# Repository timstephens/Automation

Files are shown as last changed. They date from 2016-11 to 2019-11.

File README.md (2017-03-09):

# Automation
Home automation and monitoring based on MQTT and ESP8266. There are a series of nodes, which can function as a producer or consumer of messages (or both). Right now, there are three types of node:

* Temperature sensor nodes, which have a small temperature sensor and broadcast the reading every few seconds (a PCB exists for these).
* Switcher nodes, which contain a relay to switch stuff on and off (a PCB exists for low-voltage switching)
* Message board nodes, which contain an LED matrix display so that output can be communicated to the real world.

These nodes each connect to an MQTT broker, which could be something like Mosquitto running on a Raspberry Pi. There's then some glue logic that needs to exist (e.g. NodeRed) that allows the whole system to respond to changes on the inputs. Some work is requred to get all this working, and this is left as an exercise for the student.

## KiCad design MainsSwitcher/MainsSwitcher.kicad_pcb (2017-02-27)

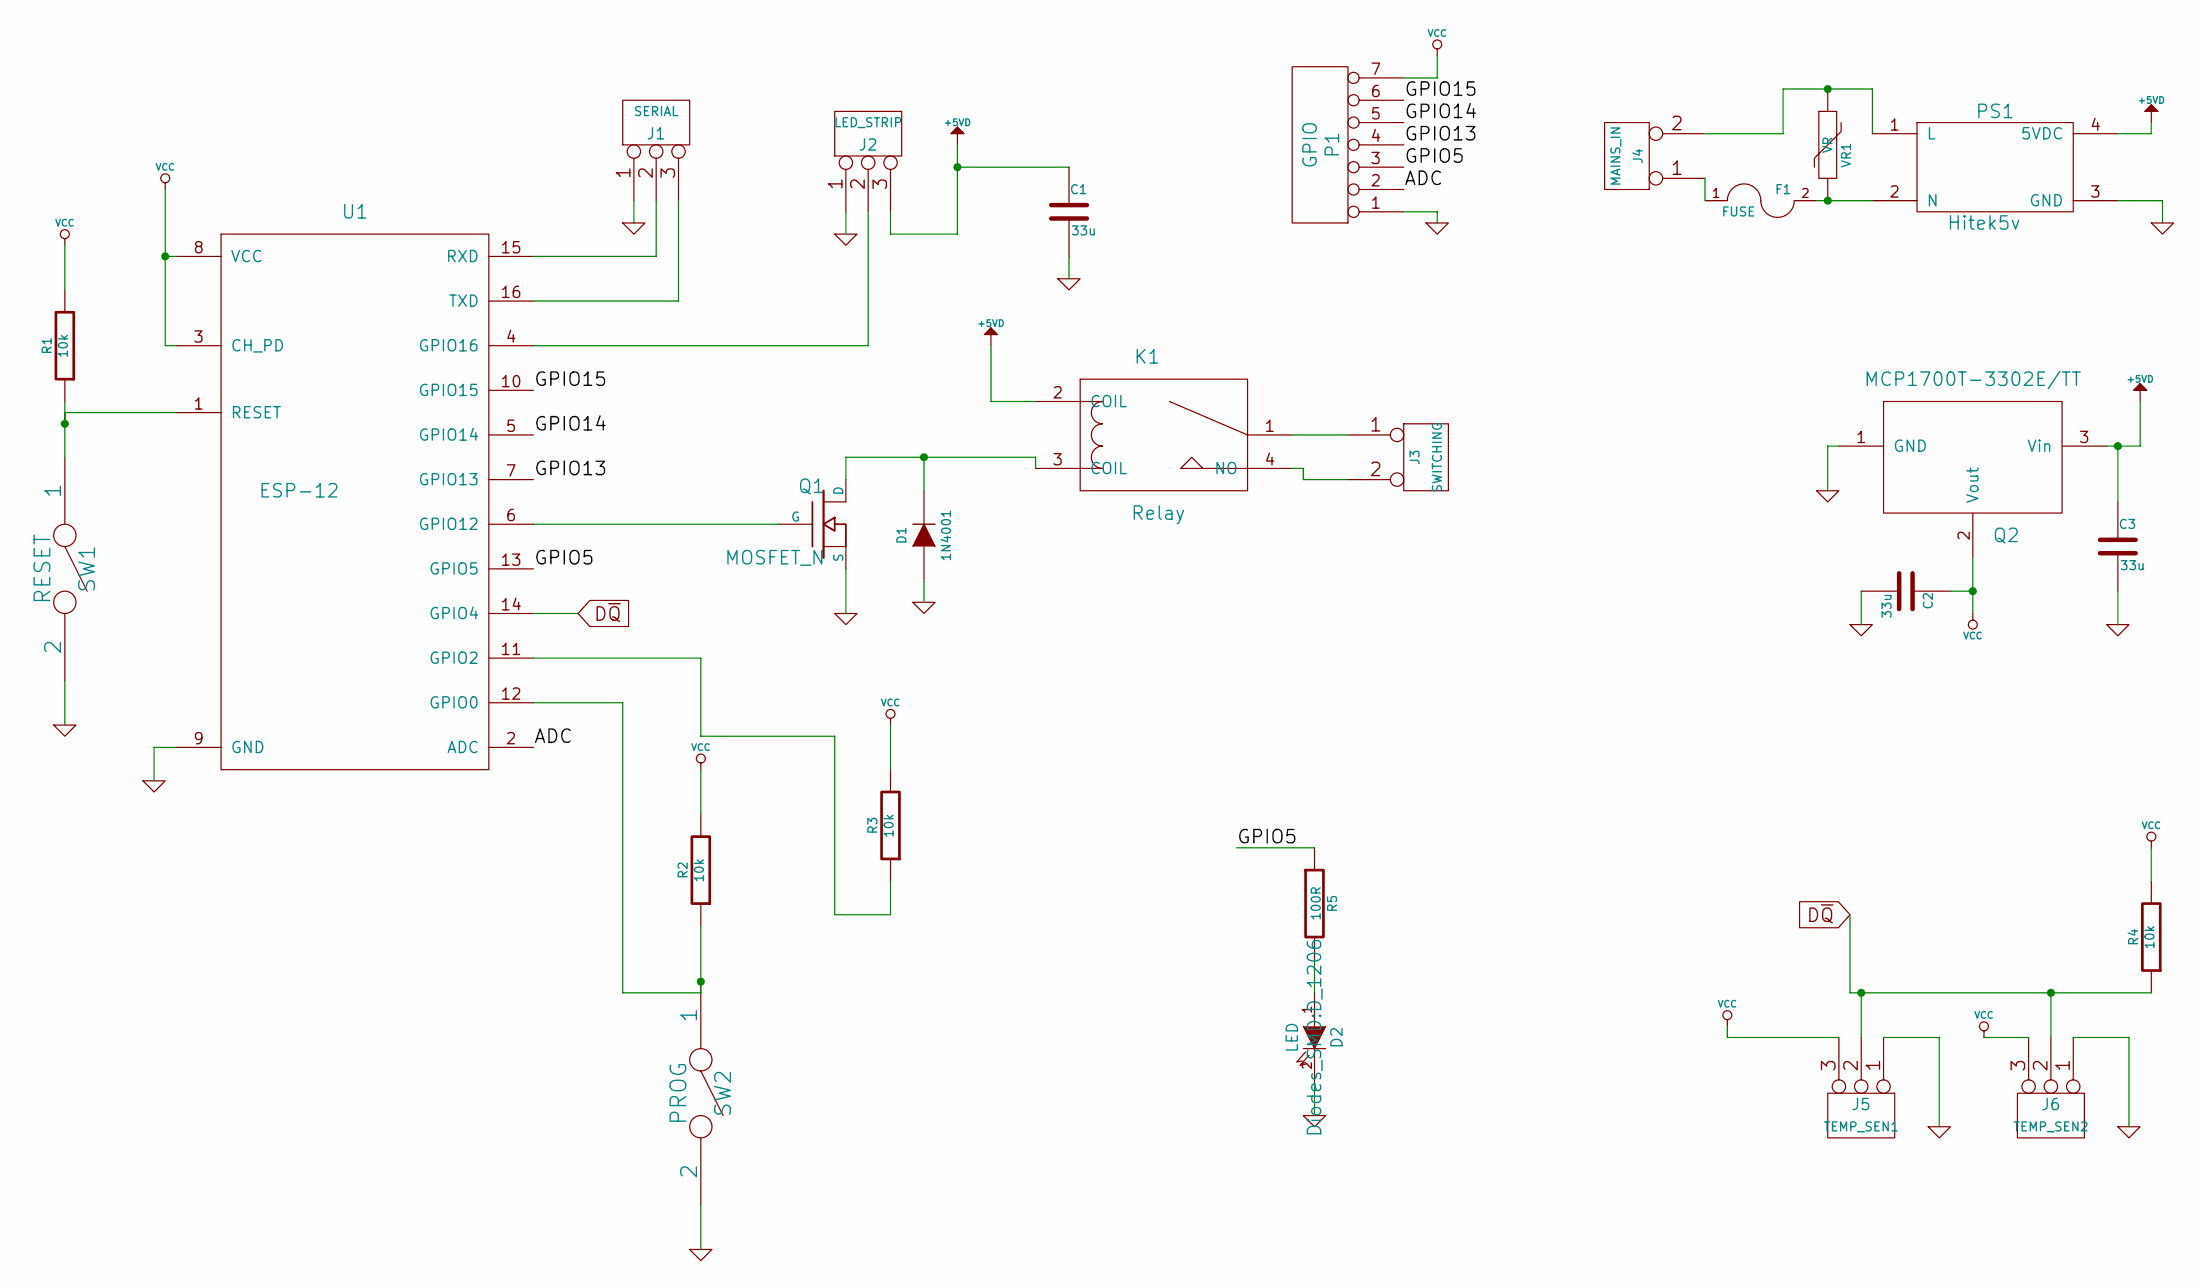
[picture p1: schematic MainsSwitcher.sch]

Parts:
C1, C2, C3: 33u; C_1206_HandSoldering
D1: 1N4001; D_SMA-SMB_Universal_Handsoldering
D2: LED; D_1206
F1: FUSE; Schurter_Fuseholder(20x5mm)0031.8211
J1: SERIAL; Molex_KK-6410-03_03x2.54mm_Straight
J2: LED_STRIP; Molex_KK-6410-03_03x2.54mm_Straight
J3: SWITCHING; PhoenixContact_PT1,5-2-5.0-V
J4: MAINS_IN; PhoenixContact_PT1,5-2-5.0-V
J5: TEMP_SEN1; Molex_KK-6410-03_03x2.54mm_Straight
J6: TEMP_SEN2; Molex_KK-6410-03_03x2.54mm_Straight
K1: Relay; COTO_SIP_ReedRelay-9007-05-00
P1: GPIO; Molex_KK-6410-07_07x2.54mm_Straight
PS1: Hitek5v; HLK-P0X
Q1: MOSFET_N; SOT-23_Handsoldering
Q2: MCP1700T-3302E/TT; SOT-23
R1, R2, R3, R4: 10k; R_1206_HandSoldering
R5: 100R; R_1206_HandSoldering
SW1: RESET; SW_PUSH_6mm
SW2: PROG; SW_PUSH_6mm
U1: ESP-12
VR1: VR; MOV-EPCOS-B72214S0421K101

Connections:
+5VD: C1.1, C3.1, J2.3, K1.2 (COIL), PS1.4 (5VDC), Q2.3 (Vin)
/ADC: P1.2, U1.2 (ADC)
/GPIO5: P1.3, R5.1, U1.13 (GPIO5)
/GPIO13: P1.4, U1.7 (GPIO13)
/GPIO14: P1.5, U1.5 (GPIO14)
/GPIO15: P1.6, U1.10 (GPIO15)
D~Q: J5.2 (PM), J6.2 (PM), R4.1, U1.14 (GPIO4)
GND: C1.2, C2.2, C3.2, D1.1 (A), D2.2 (K), J1.1, J2.1, J5.1, J6.1, P1.1, PS1.3 (GND), Q1.S, Q2.1 (GND), SW1.2, SW2.2, U1.9 (GND)
unnamed: D1.2 (K), K1.3 (COIL), Q1.D
unnamed: D2.1 (A), R5.2
unnamed: F1.1, J4.1
unnamed: F1.2, PS1.2 (N), VR1.2
unnamed: J1.2 (PM), U1.15 (RXD)
unnamed: J1.3, U1.16 (TXD)
unnamed: J2.2 (PM), U1.4 (GPIO16)
unnamed: J3.1, K1.1
unnamed: J3.2 (PM), K1.4 (NO)
unnamed: J4.2 (PM), PS1.1 (L), VR1.1
unnamed: Q1.G, U1.6 (GPIO12)
unnamed: R1.1, SW1.1, U1.1 (RESET)
unnamed: R2.1, SW2.1, U1.12 (GPIO0)
unnamed: R3.1, U1.11 (GPIO2)
VCC: C2.1, J5.3, J6.3, P1.7, Q2.2 (Vout), R1.2, R2.2, R3.2, R4.2, U1.3 (CH_PD), U1.8 (VCC)

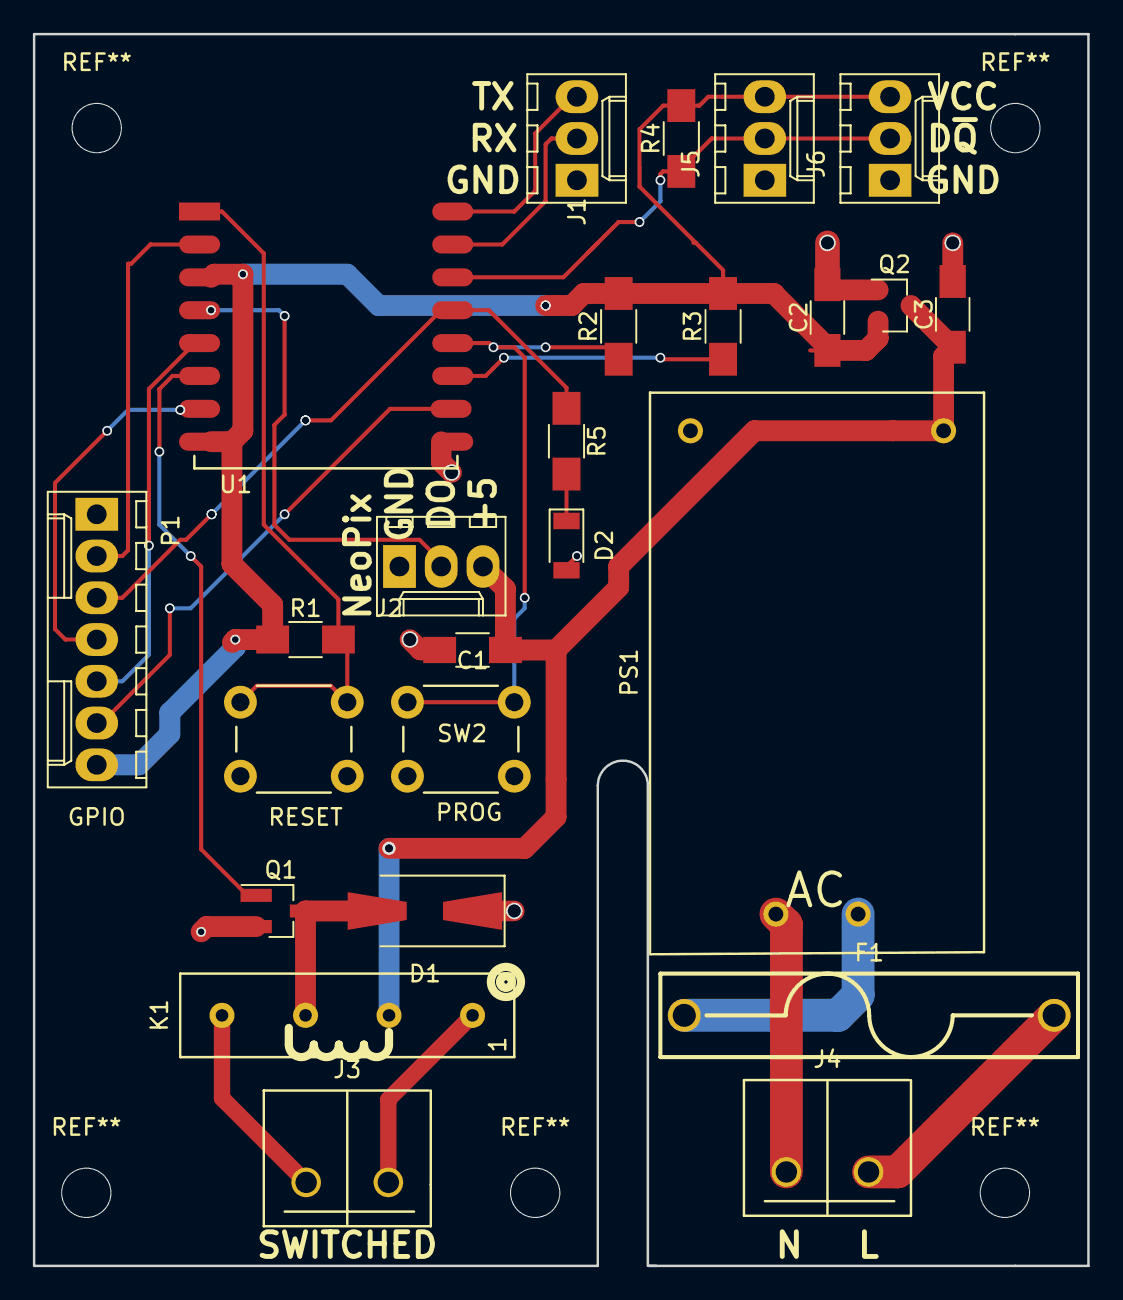
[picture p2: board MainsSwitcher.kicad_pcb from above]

Board: 2 copper layers, 64.1 x 74.9 mm, 25 parts (0 on the bottom side), 23 nets.

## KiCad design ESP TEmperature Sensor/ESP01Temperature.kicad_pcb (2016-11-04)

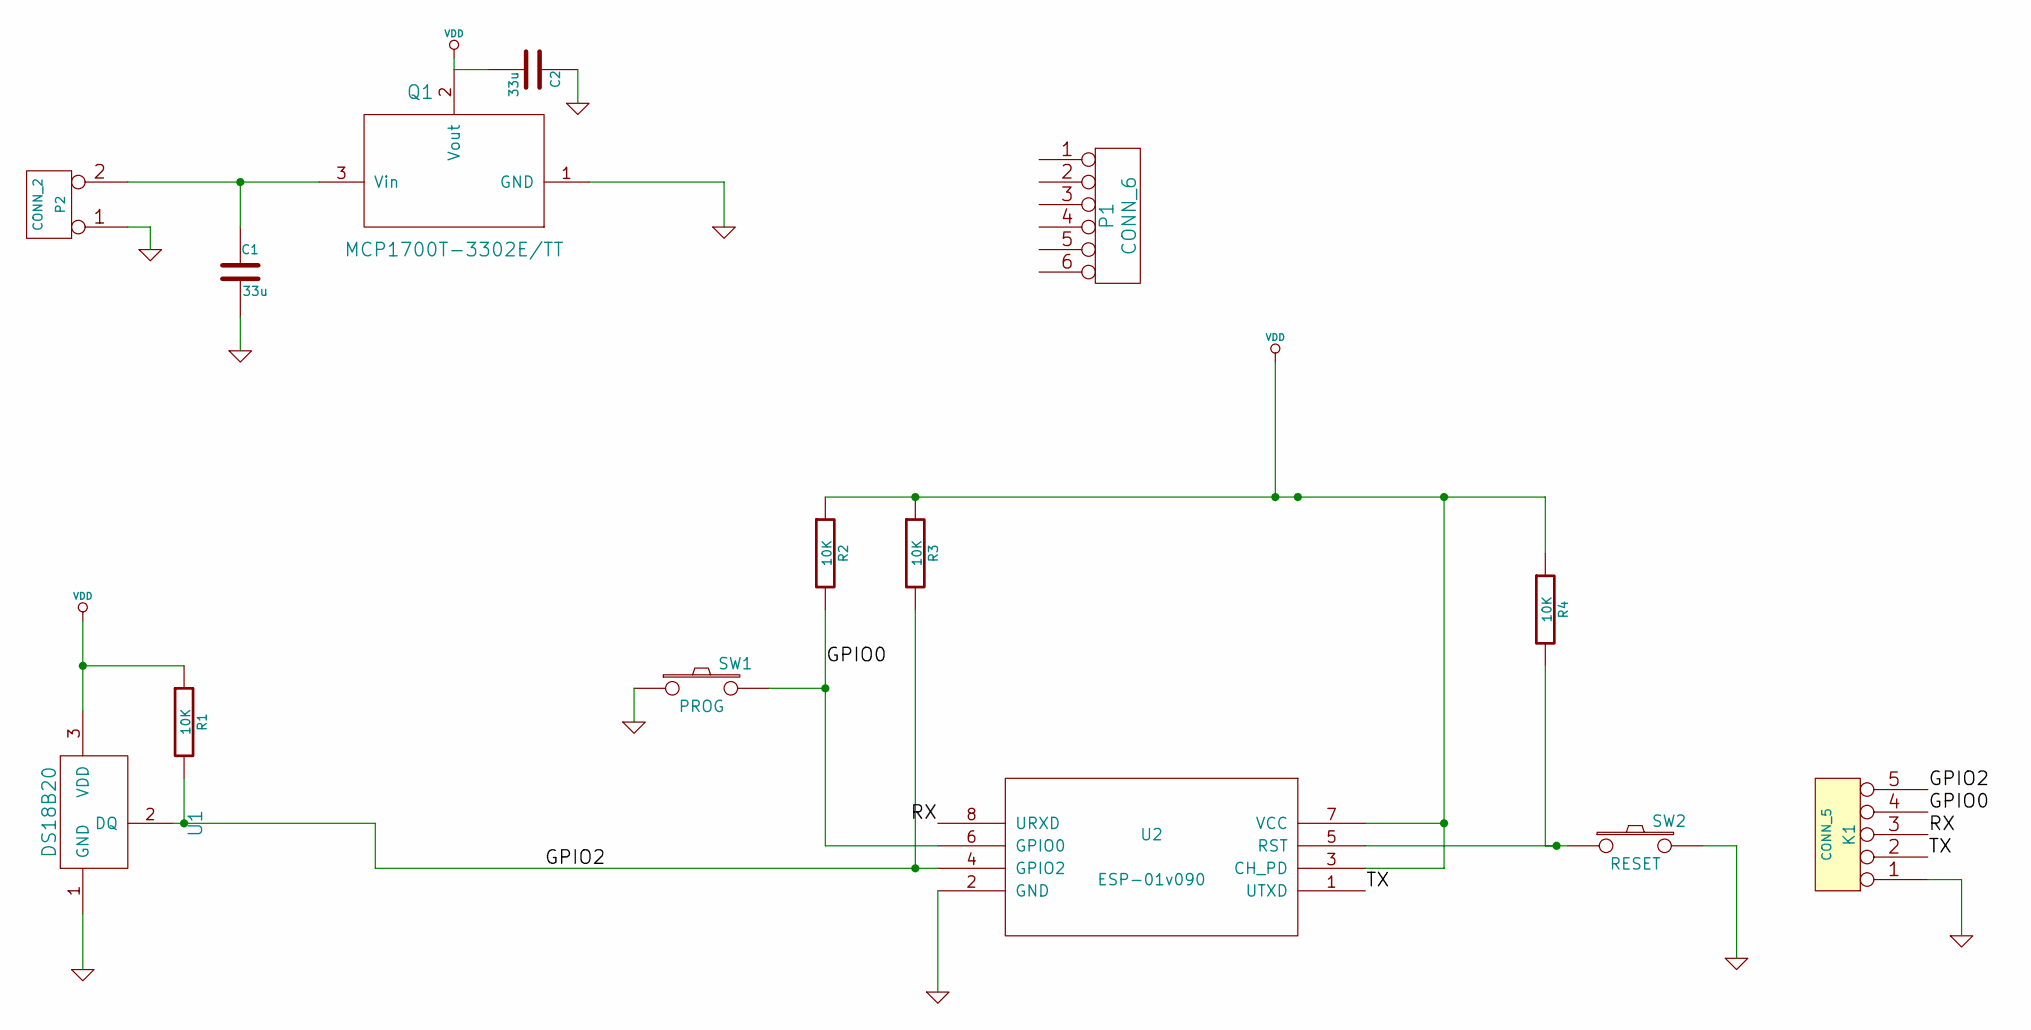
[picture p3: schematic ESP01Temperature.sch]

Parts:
C1, C2: 33u; C_1206_HandSoldering
K1: CONN_5; Molex_KK-6410-05_05x2.54mm_Straight
P1: CONN_6; Molex_KK-6410-06_06x2.54mm_Straight
P2: CONN_2; Pin_Header_Angled_1x02
Q1: MCP1700T-3302E/TT; SOT-23
R1, R2, R3, R4: 10K; R_1206_HandSoldering
SW1: PROG; SW_PUSH_6mm
SW2: RESET; SW_PUSH_6mm
U1: DS18B20; TO-92_Molded_Narrow
U2: ESP-01v090; ESP-01

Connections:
/GPIO0: K1.4, R2.2, SW1.2, U2.6 (GPIO0)
/GPIO2: K1.5, R1.2, R3.2, U1.2 (DQ), U2.4 (GPIO2)
/RX: K1.3, U2.8 (URXD)
/TX: K1.2, U2.1 (UTXD)
GND: C1.2, C2.1, K1.1, P2.1, Q1.1 (GND), SW1.1, SW2.2, U1.1 (GND), U2.2 (GND)
unnamed: C1.1, P2.2 (PM), Q1.3 (Vin)
unnamed: R4.2, SW2.1, U2.5 (RST)
VDD: C2.2, Q1.2 (Vout), R1.1, R2.1, R3.1, R4.1, U1.3 (VDD), U2.3 (CH_PD), U2.7 (VCC)

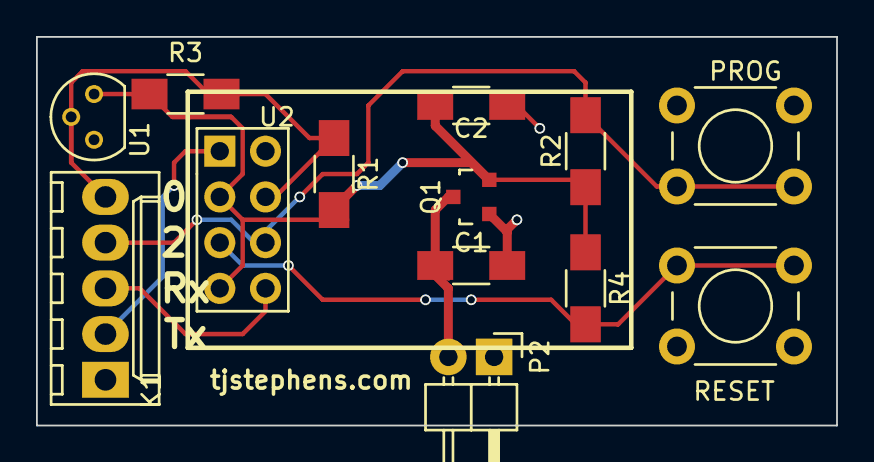
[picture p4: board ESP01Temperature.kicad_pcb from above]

Board: 2 copper layers, 44.4 x 21.6 mm, 13 parts (0 on the bottom side), 8 nets.

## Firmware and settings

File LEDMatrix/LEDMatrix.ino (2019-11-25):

#include "LedControl.h"
#include "font.h"
#include <WiFiClient.h>
#include <ESP8266mDNS.h>
#include <PubSubClient.h>

const char* ssid = "virginmedia0465902";
const char* password = "hunter77";
////MDNSResponder mdns;

String pl; //Somewhere to store the data forthe display?
#define ARRAYCOLS 128
#define NUMARRAYS  8
#define DISPLENGTH 10
// Parameters in LedControl are DIN, CLK, CS
//LedControl lc = LedControl(12, 11, 10, NUMARRAYS);// ARDUINO VERSION
LedControl lc = LedControl(14, 13, 12, NUMARRAYS); //ESP03  Version

/* we always wait a bit between updates of the display */
unsigned long delaytime = 500;

//Button on GPIO 2, pulled high with 470k. Short to ground to register a button press.
int button = 2;

// Update these with values suitable for your network.
byte mac[]    = {  0xDE, 0xED, 0xBA, 0xFE, 0xFE, 0xED };
//IPAddress ip(192.168.0.9);
IPAddress server(192, 168, 0, 8);
//8*************
void callback(char* topic, byte* payload, unsigned int length) {
  pl = ""; //This is a global string because Arduino.
  Serial.print("Message arrived [");
  Serial.print(topic);
  Serial.print("] ");
  for (int i = 0; i < length; i++) {
    Serial.print((char)payload[i]);
    pl += String((char)payload[i]);
  }
  Serial.println();
}

WiFiClient ethClient;
PubSubClient client(ethClient);

void reconnect() {
  // Loop until we're reconnected
  while (!client.connected()) {
    Serial.print("Attempting MQTT connection...");
    // Attempt to connect
    if (client.connect("arduinoClient")) {
      Serial.println("connected");
      // Once connected, publish an announcement...
      client.publish("/control", "/message ready");
      // ... and resubscribe
      client.subscribe("/message");
    } else {
      Serial.print("failed, rc=");
      Serial.print(client.state());
      Serial.println(" try again in 5 seconds");
      // Wait 5 seconds before retrying
      delay(5000);
    }
  }
}

//***************************



void setup() {
  Serial.begin(115200);
  Serial.println("connected");
  
  /*
    The MAX72XX is in power-saving mode on startup,
    we have to do a wakeup call
  */
  for (int devices = 0; devices < NUMARRAYS; devices++)
  {
    lc.shutdown(devices, false);

    /* Set the brightness to a medium values */
    lc.setIntensity(devices, NUMARRAYS);
    /* and clear the display */
    lc.clearDisplay(devices);
  }
  WiFi.begin(ssid, password);
  while (WiFi.status() != WL_CONNECTED) {
    delay(500);
    Serial.print(".");
  }//*/

  client.setServer(server, 1883);
  client.setCallback(callback);
  pinMode(button, INPUT);
}

void printChar(String row1Data) {

  /* ****************************************************
    Build up the text that you want to write to the screen
    into a buffer, made up of ARRAYCOLS chars (corresponding to a
    column each).
    Then write the buffer out to the display, reconfiguring
    it as appropriate for the display layout.

    TODO: NEEDS SOME VALIDATION TO PREVENT BUFFER OVERFLOW
  **************************************************** */

  char buf[ARRAYCOLS];
  int c, i, count;
  int array, col;

  //Initialise the buffer so it's all zeros when we begin
  memset(buf, 0, sizeof(buf));

  count = 0; //counter for the current buffer position
  //String row1Data = "test";
  //For each character
  for (int index = 0; index < row1Data.length(); index++) {
    c = row1Data.charAt(index);
    for (int i = 0; i < 6; i++) { //For each column within a character
      if (count > ARRAYCOLS) {
        break;  //Once there are more columns than in the LED array, stop writing. This is to stop a crasher on ESP03
      }
      buf[count] =  pgm_read_byte(&ASCII[(int)c][i]); //We're bit-shifting the data in one column at a time
      count++;
    }


  }
  //Once the buffer is full, write the data out to the LED array
  //There are 64 columns, so do a modulus%8 of the current index in the buffer. The mod is the array number and the remainder is the column.
  for (int i = 0; i < ARRAYCOLS; i++) {
    array = i / 8;
    col = 7 - (i % 8); //The column order is the reverse of the display order, so need to reverse it here by subtracting from 7.
    //i.e. col7 needs to be sent as col 1, etc.
    lc.setColumn(array, col, buf[i]);
  }
}


void loop() {
  int pos;


  //If there's a message that's longer than the display length, we'll scroll through it once, then display the first few characters on the display until it's updated again.
  //This means that you'll need to handle this case on the MQTT server end (probably within NodeRed, or whatever)
  if (pl.length() > DISPLENGTH) {
    pos = DISPLENGTH;
    Serial.println("Scrolling...");

    while (pos <= pl.length()) {
      printChar(pl.substring(pos - DISPLENGTH, pos));
      pos++;
      delay(500);
    }
    delay(1000);
    pl = pl.substring(0, DISPLENGTH); //Do this so that a long string can't prevent the pl from being updated. A long strng could cause the code to be stuck in this loop for ages because the window where a new string can be sent is very whort.

  }

  printChar(pl);  //str(payload) should return a string from the payload, assuming that the payload is null terminated...
  
  
  //If there's a button press, send a message to tell the broker that it's happened. A decision about what that means will be made there...
  int inputButton = digitalRead(button);
  
  if (inputButton == 0) {
    client.publish("/buffer", "button");  //Publish that a button was pressed, and signal it to the buffer workflow in Nodered.
  } else {
    Serial.println("buttonUp");
  }
  
  delay(1000);
  //  for (int devices = 0; devices < NUMARRAYS; devices++) {
  //    lc.clearDisplay(devices);
  //  }
  Serial.println("Main Loop");
  if (!client.connected()) {
    reconnect();
  }
  client.loop();
}

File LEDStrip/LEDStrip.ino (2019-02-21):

#include <Adafruit_NeoPixel.h>
#include <WiFiClient.h>
//#include <ESP8266mDNS.h>
#include <PubSubClient.h>
#include <DallasTemperature.h>
#include <OneWire.h>
#include <ESP.h>
#include <ESP8266WebServer.h>
#include <EEPROM.h>

#include "wifiSetup.h"

#define LED_PIN 4
#define ONE_WIRE_BUS 5
//Set up the NeoPixel Library

#define LED_STRIP 16
#define NUMPIXELS      5
Adafruit_NeoPixel pixels = Adafruit_NeoPixel(NUMPIXELS, LED_STRIP, NEO_GRB + NEO_KHZ800);

int delayval = 500; // delay for half a second


//Turn on the temperature sensors
OneWire oneWire(ONE_WIRE_BUS);
DallasTemperature sensors(&oneWire);


// Update these with values suitable for your network.
IPAddress server(192, 168, 0, 8);  //Default, but is set on 'connect' from values stored in the EEPROM

void callback(char* topic, byte* payload, unsigned int length) {

  Serial.print("Got message :");
  for (int i = 0; i < length; i++) {
    Serial.print((char)payload[i]);
  }
  Serial.println();
}

WiFiClient ethClient;
PubSubClient client(ethClient);

void reconnect() {
  //This connects to the MQTT broker
  // Loop until we're reconnected
  while (!client.connected()) {
    Serial.print("Attempting MQTT connection...");
    // Attempt to connect
    if (client.connect(clientName.c_str())) {
      Serial.println("connected");
      // Once connected, publish an announcement...
      client.publish("/control", clientName.c_str());
      // ... and resubscribe
      client.subscribe("/control/#");
    } else {
      //      Serial.print("failed, rc=");
      //      Serial.print(client.state());
      //      Serial.println(" try again in 5 seconds");
      // Wait 5 seconds before retrying
      delay(5000);
    }

    //The code gets trapped in this loop if the network settings are not correct, or if the broker IP is wrong. Provide an opportunity to escape to the settings server
    if (digitalRead(0) == 0) {
      startSoftAP();
    }
    if (serverStatus == 1) {
      configServer.handleClient();
    }
  }
}

//***************************


void setup() {

  EEPROM.begin(512); //Begin the EEPROM session

  int host1, host2, host3, host4; //the IP addresses of the mqtt broker.
  serverStatus = 0; //This is the default case, where there is no server started for config.
  Serial.begin(115200);
  //  Serial.println("connected");

  //Generate the MQTT clientname from the MAC Address.
  uint8_t mac[6];
  WiFi.macAddress(mac);

  //  String dn;
  //  for (int i = deviceNameAddr; i < 32; ++i)
  //  {
  //    dn += char(EEPROM.read(i));
  //  }

  clientName += "LEDStrip-";
  clientName += macToStr(mac);

  connectToWiFi();

  if (WiFi.status() != WL_CONNECTED) {
    //Need to serve up a page that offers the opportunity to enter server details etc.
    //    Serial.println("Failed to connect to WiFi netowrk.");
    //    Serial.println("Change to configuration mode");

    // Start the server
    startSoftAP();  //sets serverStatus = 1;



  } else {
    //Serial.println("Connected to WiFi network ");
    //Serial.println(esid);
    client.setServer(server, 1883);
    client.setCallback(callback);
    //Stop the softAP if it's running, and disconnect all stations.
    //WiFi.softAPdisconnect(true);
  }
  //Setup the MQtt broker.
  host1 = EEPROM.read(IPAddr);  //Get the IP Address.
  host2 = EEPROM.read(IPAddr + 4);
  host3 = EEPROM.read(IPAddr + 8);
  host4 = EEPROM.read(IPAddr + 12);
  server = IPAddress(host1, host2, host3, host4);
  // Serial.print("Broker IP=");
  //Serial.println(server);
  //  //Start the temperature sensor


  //Serial.print("Number DS18b20 devices: ");
  //Serial.println(sensors.getDeviceCount(), DEC);
  //setup some IO on various pins
  pinMode(LED_PIN, OUTPUT);

  pixels.begin(); // This initializes the NeoPixel library.
  sensors.begin(); //initialise the temperature sensors
}


void loop() {
  if (WiFi.status() != WL_CONNECTED) {
    connectToWiFi();
  }

  if (serverStatus == 0) {  //Only want to handle the webserver configuration stuff if it's running, so this handles the case if it's not.
    char buffer[10];
    sensors.requestTemperatures();
    // After we get the temperatures, we can print them here.
    // We use the function ByIndex, and as an example get the temperature from the first sensor only.
    for (int i = 0; i < sensors.getDeviceCount(); i++) {
      Serial.print("Temperature for the device ");
      Serial.print(i, DEC);
      Serial.println(" is: ");
      Serial.println(sensors.getTempCByIndex(i));
      String tempC = String(sensors.getTempCByIndex(i));

      if (!client.connected()) {
        reconnect();
      } else {
        Serial.println("Publishing");
        String publishTopic = "/temperature/";
        publishTopic += clientName;
        publishTopic += "/";
        publishTopic += i; //Append the sensor number to the channel data
        client.publish(publishTopic.c_str(), (char *)tempC.c_str());
        delay(2000);

        //TODO: Fix this deepsleep bug
        //Serial.println("Done, Sleeping 10s");

        //ESP.deepSleep(10000000, WAKE_RF_DEFAULT);
      }
    }

    client.loop();

  } else {
    //Serial.printf("Stations connected = %d\n", WiFi.softAPgetStationNum());
    configServer.handleClient();
  }
  if (digitalRead(0) == 0) {
    //Serial.println("Prog pushed, running config server");
    startSoftAP();
  }


  for (int i = 0; i < NUMPIXELS; i++) {

    // pixels.Color takes RGB values, from 0,0,0 up to 255,255,255
    pixels.setPixelColor(i, pixels.Color(0, 150, 0)); // Moderately bright green color.

    pixels.show(); // This sends the updated pixel color to the hardware.

    delay(delayval); // Delay for a period of time (in milliseconds).

  }
  delay(2000);
}

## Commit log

2015-04-27 Initial Commit
    MQTT_Publish contains some code that connects to a mosquitto server and
    publishes the temperature measured on a DS18B20. The code then holds a
    delay and pushes an update every 10s. The whole thing may or may not
    work depending on whether the connection remains open or not. A version
    very similar to this (but without the ESP.deepsleep() on line 96 worked
    for 10hours without failure in the initial test.
2015-06-29 Add SensorTelemetry
    which is supposed to be able to get the temperature from a DHT22 T/H
    sensor and send it over RF24 link.
2015-07-08 Add new receiver code
    Not yet functional —receiver does not appear togged anything from
    radio.available on the pong side of the system.
    Radio on ping side claims about 50% success rate. Something is fibbing
    to me…
2015-07-18 LED Matrix as first step towards MQTT display
    LED Matrix allows writing of arbitrary characters to a set of LED
    matrix displays controlled by MAX7219 chips. The particular orientation
    of the displays may differ (they’re from eBay).
    Added font.h, which is cribbed from
    http://www.hwsw.no/snippets/5x7_LCD_font.php
    NB: To run this on an ESP8266, you need to make a change like this to
    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
2015-07-19 Working display of millis() on ESP8266
2015-07-19 Wifi connection works, broker connection fails
    WiFi network connection starts up with the system, and remains up (ping
    proves this).
    Added MQTT stuff, but there’s nothing working here. Issue seems to be
    that it doesn’t connect to the broker (or fails). Nothing shows on
    mosquito_sub on the broker end either, so it’s a double-ended fail.
    Counter increments (slowly) since there’s a delay incurred with
    connecting to the broker, and then failing.
    [LEDMatrix.ino]
2015-07-20 rename client to prevent naming clash
    created function to clear displays
    More debugging
    [LEDMatrix.ino]
2015-08-24 Trying to get the wifi and broker to connect
    [LEDMatrix.ino]
2015-08-24 Revert 3d2e02d..628b364
    This rolls back to commit 3d2e02dde2a0b45e62e666465407c8845c5f7a7e.
    [LEDMatrix.ino]
2016-03-28 Working to display millis(), and connects to wifi
2016-03-28 Getting there
    LED Matrix displays millis()
    Connects to WiFi and MQTT broker, publishes and receives messages with
    confirmation through Serial connection
    [LEDMatrix.ino]
2016-03-28 Working MQTT publishing to LED Matrix display
2016-03-28 Working with full LED matrix
    Includes a validation element to catch the case when the buffer
    overflows.
2016-04-06 Added a temperature sensor node
    UNTESTED. Not yet uploaded to an ESP to confirm that it’s behaving…
2016-04-16 Working for DHT11, apart from the DHT11 part
    There’s something screwy with the DHT11 that I have, or my wiring for
    it, or the power supply to it. For this reason, it’s not returning
    sensible data. The data that it does return is faithfully published on
    MQTT though…
2016-08-20 Adding code to handle button
    Hardware works with the modifications required for this code.
2016-10-10 Working temperature broadcast
    Using DS18b20 sensor, this is actually working again!
2016-10-16 Sleeping enabled
    5 minute sleep after successfully posting a temperature report
2016-10-17 PCB for temperature sensor
    [ESP01Temperature.kicad_pcb, ESP01Temperature.sch]
2016-11-04 PCB Design
    Kicad design files for build PCB
    [ESP01Temperature.kicad_pcb, ESP01Temperature.sch]
2016-11-06 SSID/Password config by web page
    Added code to use ESP8266Websserver to offer a page to allow a client
    to connect to configure the wifi settings.
    This code still assumes that the MQTT server will exist at a fixed IP
    (needs a DNS resolver adding to fix this), and perhaps a method to
    configure the hostname and store it to EEPROM.
    TODO
    =====
    * Add config for hostname
    * Break the config stuff out into a separate header file for
    portability to other projects
    * Kill off the vestigial commented lines from old attempts at stuff
    [temperatureSensor.ino]
2016-11-12 Config server, and sleep
    Configuration web server that opens a soft access point, and offers a
    webpage that allows configuration of the SSID, password for the main
    wifi network, and IP address of the MQTT broker.
    Needs some tidying up of the page, and proper handler that returns some
    sort of configuration confirmation, etc.
    Once correctly connected, sends the temperature reading from the
    DS18b20, and then sleeps for 5 minutes, ad infinitum.
    [temperatureSensor.ino]
2016-11-13 Updated config form, removed sleep
    The code isn’t waking from deepsleep. It seems like there’s a bug in
    the code somewhere, so I don’t know if this is solvable.
    [temperatureSensor.ino]
2016-11-13 Revert "Config server, and sleep"
    This reverts commit aa25cd490c7b3ed2b0cc843134b077d644cdfd3d.
    # Conflicts:
    # temperatureSensor/temperatureSensor.ino
    [temperatureSensor.ino]
2016-11-13 Revert "Revert "Config server, and sleep""
    This reverts commit 66553d52c90a2edec54f977f60f120cf252b75a4.
    [temperatureSensor.ino]
2017-02-15 First stab at switch responder
    Modified the code so that the device should respond to calls on the
    /control topic and switch the state of an IO pin.
2017-02-16 Delete a couple of unused items
    Files that were only there for debugging - removed them.
2017-02-26 Circuitboard for Mains Switcher
    PCB for the Multi-switcher design. Can accept volt free switching via
    relay, WS8212, some free GPIO.
    Powered from HLK-P01 5v psu connected to the mains on board.
    [MainsSwitcher.kicad_pcb, MainsSwitcher.sch]
2017-02-27 Added fuseholder
    Fuseholder added to the mains inlet. As ordered.
    [MainsSwitcher.kicad_pcb, MainsSwitcher.sch]
2017-03-04 Compiles, doesn't run
    Gives a fatal exception on the Serial output once it’s finished
    uploading.
    [GPSwitcher.ino]
2017-03-04 Moved around the TempSensor node for more reliability too
    Matches what is in the GP Switcher node.
2017-03-04 Forgot to add the reliability code
    Added reliability code to the loop() of TemperatureSensor.
2017-03-05 Updated the TempSensor
    code now refactored to be a bit neater…
2017-03-13 multiple sensors on TempSensor
    Added the ability for the TempSensor to address multiple DS18b20s.
    It’ll report the value of each in a different sub-topic.
    These ought to be deterministic, so should always have the same
    relationship...
2017-03-22 Working and installed
    Couple of changes to accommodate a layout error on the PCB (GPIOs are
    incorrectly identified on library part)
    Made the code that sets the relay more generic (uses constants rather
    than pin numbers at point of use).
    [GPSwitcher.ino]
2019-02-21 Changes to who knows what.
    Uncommitted changes to stuff. Tidying up…
    [ESP01Temperature.sch, MainsSwitcher.sch]
